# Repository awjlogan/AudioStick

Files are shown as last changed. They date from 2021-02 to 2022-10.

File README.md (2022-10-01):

# AudioStick

Quality audio carrier board for the Raspberry Pi Zero. A self facilitating media node.

## Description and Getting Started

This board is designed to be used with a Raspberry Pi Zero (W) to turn it into small high quality streaming audio device. It incorporates a soft power switch, which makes it easier to use in normal settings (e.g., don't need to SSH in to shutdown) and prolong the life of the SD card. The AudioStick connects directly to the standard Raspberry Pi 40pin GPIO header.

All design files and source code are under the [_Don't Be A Dick_][dbad-github] license.

### Installation on the Raspberry Pi

From a clean installation of Raspbian, log in to your Raspberry Pi and run the following 3 lines:

```shell
> sudo apt install git
> git clone https://github.com/awjlogan/audiostick.git
> cd ./audiostick
> sudo ./audiostick_setup.sh
```

The `audiostick_setup.sh` script will:
 - Install the PCM5102's configuration in the boot configuration
 - Add the `asound.conf` configuration file
 - Add the power control service
 - Shutdown the Raspberry Pi

When it is complete, you will need to remove and reconnect the power before powering on again.

### Using the AudioStick

 - When the AudioStick is off, there is no power supplied to the Raspberry Pi, so power consumption is minimised.
 - Pressing the button will power on the Raspberry Pi. The power LED will flash until the Raspberry Pi has successfully booted, at which point it will stay on.
 - To turn the AudioStick OFF, press and hold the button for at least one second. The power LED will flash until the Raspberry Pi has safely shutdown. Once the LED returns to pulsing, the Raspberry Pi is completely off and it is safe to remove the power if you wish.

### Raspberry Pi Setup

The AudioStick is intended to be used with something like MPD to allow you to connect up to any speaker (with amplifier) and get access to your local music or streaming services controlled by your phone. There are a lot of good tutorials (REVISIT add some links) available, so I won't reiterate the points here, but here are a few additional things that might be useful:

 - Change the Raspberry Pi's hostname to a meaningful name, for example `livingroompi`. This will also allow you to have multiple AudioSticks on the same network.
 - Configure your NAS (or whatever storage) to mount at boot time in `/etc/fstab`. Be aware that the system might attempt to mount the device before the network is available.
 - Disable the swap file to increase the SD card's life (`sudo apt remove dphys-swapfile`)

## Hardware

### PCB

The PCB was designed using [EAGLE][eagle-web] v9. The *.brd* and *.sch* files are provided, along with a small library of parts (*AudioStick.lbr*). A full bill of materials is provided as an *.ods* file.

### Firmware and flashing the ATtiny13A

The source for the power control microcontroller is provided, and can be compiled with the supplied Makefile. You will need to alter `Makefile` with the programmer that you are using. To compile the firmware:

`> /firmware/make`

The header **J4** on the PCB is a standard Microchip \[Atmel\] 6 pin programming header. Using your compiled firmware (or the precompiled *.hex* file), you can flash the microcontroller with e.g. an Atmel ICE. To flash the microcontroller, run:

`> /firmware/make flash`

## Change Notes

### Version 2.2

 - [x] -ELEC- Change from pogo pads to pin header for AVR ISP.

### Version 2.1

 - [x] -MECH- Mirror RasPi so connectors face Audiostick board.
 - [x] -ELEC- Move LED to PWM output pin for more interesting effects (chicken transistor in case programmer can't drive pin with LED).
 - [x] -ELEC- Remove MOSFET power switch for RasPi. Use inrush inhibitor instead.
 - [x] -ELEC- Downsize RasPi power capacitor.

### Version 2.0

Finalised release PCB, firmware, and RasPi software.

## Datasheets and useful links

- [PCM5102 DAC][pcm5102-datasheet]
- [ATtiny13A][attiny13-datasheet]

[dbad-github]: https://github.com/philsturgeon/dbad
[eagle-web]: https://www.autodesk.com/products/eagle/overview
[pcm5102-datasheet]: http://www.ti.com/product/PCM5102
[attiny13-datasheet]: https://www.microchip.com/wwwproducts/en/ATTINY13A

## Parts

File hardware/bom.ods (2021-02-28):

Designator | Description | Name | Value | Unit | Package | Quantity | Farnell code | Cost per | Cost total | DNP
C2, C4, C7, C10, C11, C12, C13, C15, C19 | Ceramic cap |  | 100 | nF | 0603 | 9 | 2581045 | £0.02 | £0.14
C16 | Ceramic cap |  | 10 | nF | 0603 | 1 |  |  |  | DNP
C3, C5, C6, C14, C17 | Ceramic cap |  | 2.2 | uF | 0603 | 3 | 3013428 | £0.11 | £0.34
C8, C9 | Film cap |  | 2.2 | nF | 0603 | 2 | 2326055 | £0.20 | £0.40
D1, D2, D3 | TVS protection diodes |  |  |  | 0603 | 3 |  |  |  | DNP
IC1 | LDO voltage regulator | AP2127 |  |  | SOT-23-5 | 1 | 3257432 | £0.29 | £0.29
IC2 | LDO voltage regulator | MCP1700 | 3.3 | V | SOT-23 | 1 | 1296592 | £0.31 | £0.31
IC3 | Audio codec | PCM5102A |  |  | SSOP-28 | 1 | 2402251 | £4.64 | £4.64
IC5 | Inrush limiter | AP22804AWS |  |  | SOT-23-5 | 1 | 2748546 | £0.50 | £0.50
IC6 | Microcontroller | Attiny13A |  |  | SOIC-8 | 1 | 1715519 | £0.66 | £0.66
J2 | 3.5mm stereo jack | n/a |  |  |  | 1 | 2579730 | £1.80 | £1.80
J3 | USB micro-B |  |  |  |  | 1 | 2668482 | £0.25 | £0.25
J4 | 2x3 1.27 mm header |  |  |  |  | 1 | 2779463 | £0.64 | £0.64
L1, L2, L3 | Ferrite bead |  |  |  | 0603 | 3 | 1115048 | £0.02 | £0.07
LED1 | LED | KPA-3010 |  |  |  | 1 | 2464007 | £0.14 | £0.14
R1, R2 | Thin film resistor |  | 470 | R | 0603 | 2 | 2614445 | £0.08 | £0.15
R4, R11 | Resistor |  | 180 | R | 0603 | 2 | 2447267 | £0.00 | £0.01
R5, R6, R7, R12, R16 | Resistor |  | 22 | R | 0603 | 5 | 2447301 | £0.01 | £0.03
R3, R9, R10, R13, R14 | Resistor |  | 10 | K | 0603 | 4 | 2447230 | £0.01 | £0.02
R8 | Resistor |  | 0 | R | 0603 | 1 |  |  |  | DNP
Raspberry Pi header | 2x20 pin socket |  |  |  |  | 1 | 2725179 | £0.23 | £0.23
SW1 | SPNO switch | EVQP7C |  |  |  | 1 | 2860917 | £0.25 | £0.25
T1 | NPN transistor | BC850 |  |  | SOT-23 | 1 | 1081239 | £0.04 | £0.25
 |  |  |  |  |  |  |  | Total (ex VAT) | £10.86
 |  |  |  |  |  |  |  | Total (inc VAT) | £13.03
 |  |  |  |  | '

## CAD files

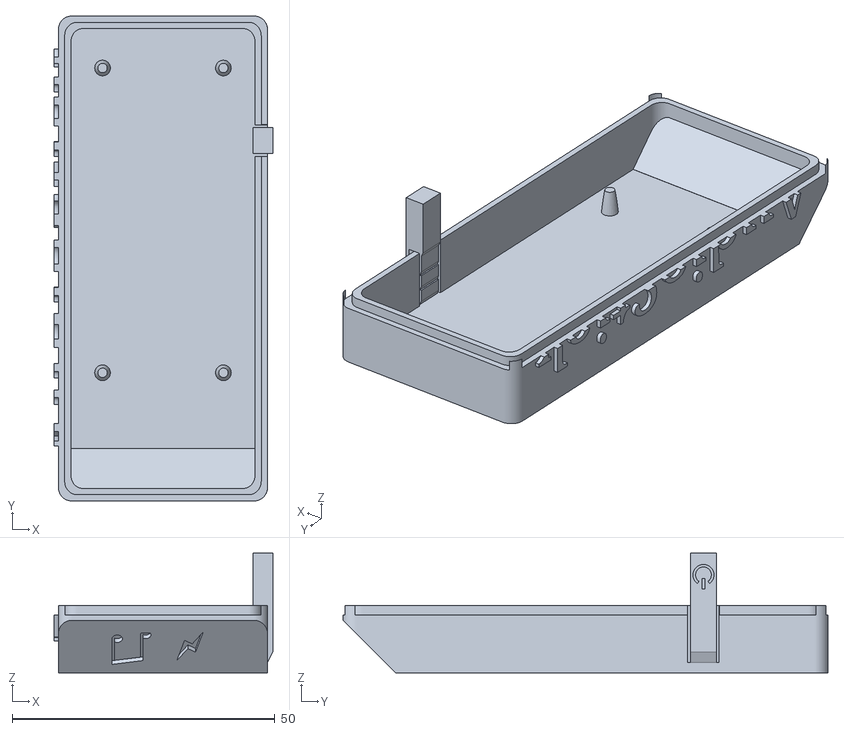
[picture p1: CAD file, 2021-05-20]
hardware/case/case_top.stl
41.6 x 92.3 x 22.8

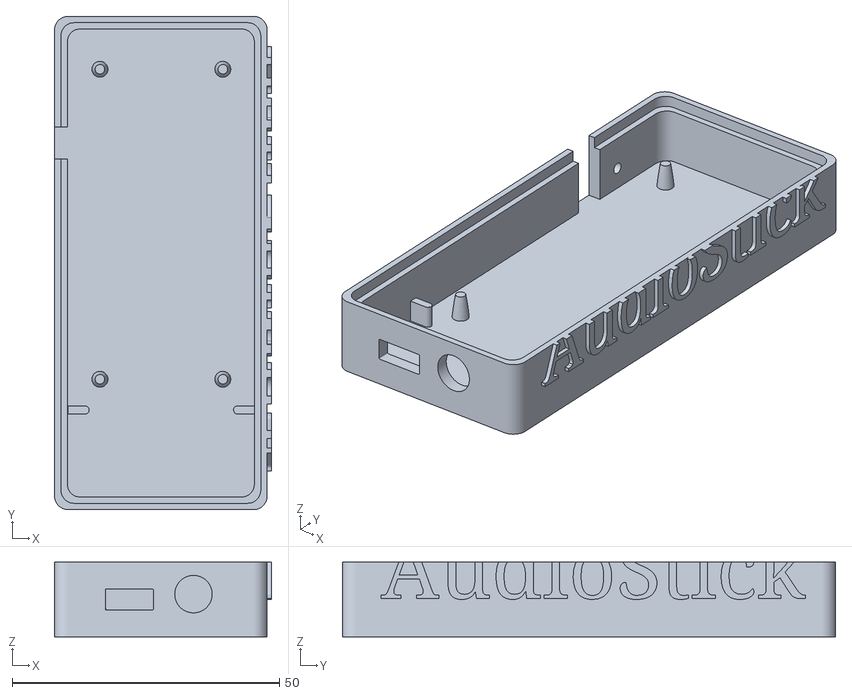
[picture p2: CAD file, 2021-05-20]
hardware/case/case_bottom.stl
40.6 x 92.3 x 14.0

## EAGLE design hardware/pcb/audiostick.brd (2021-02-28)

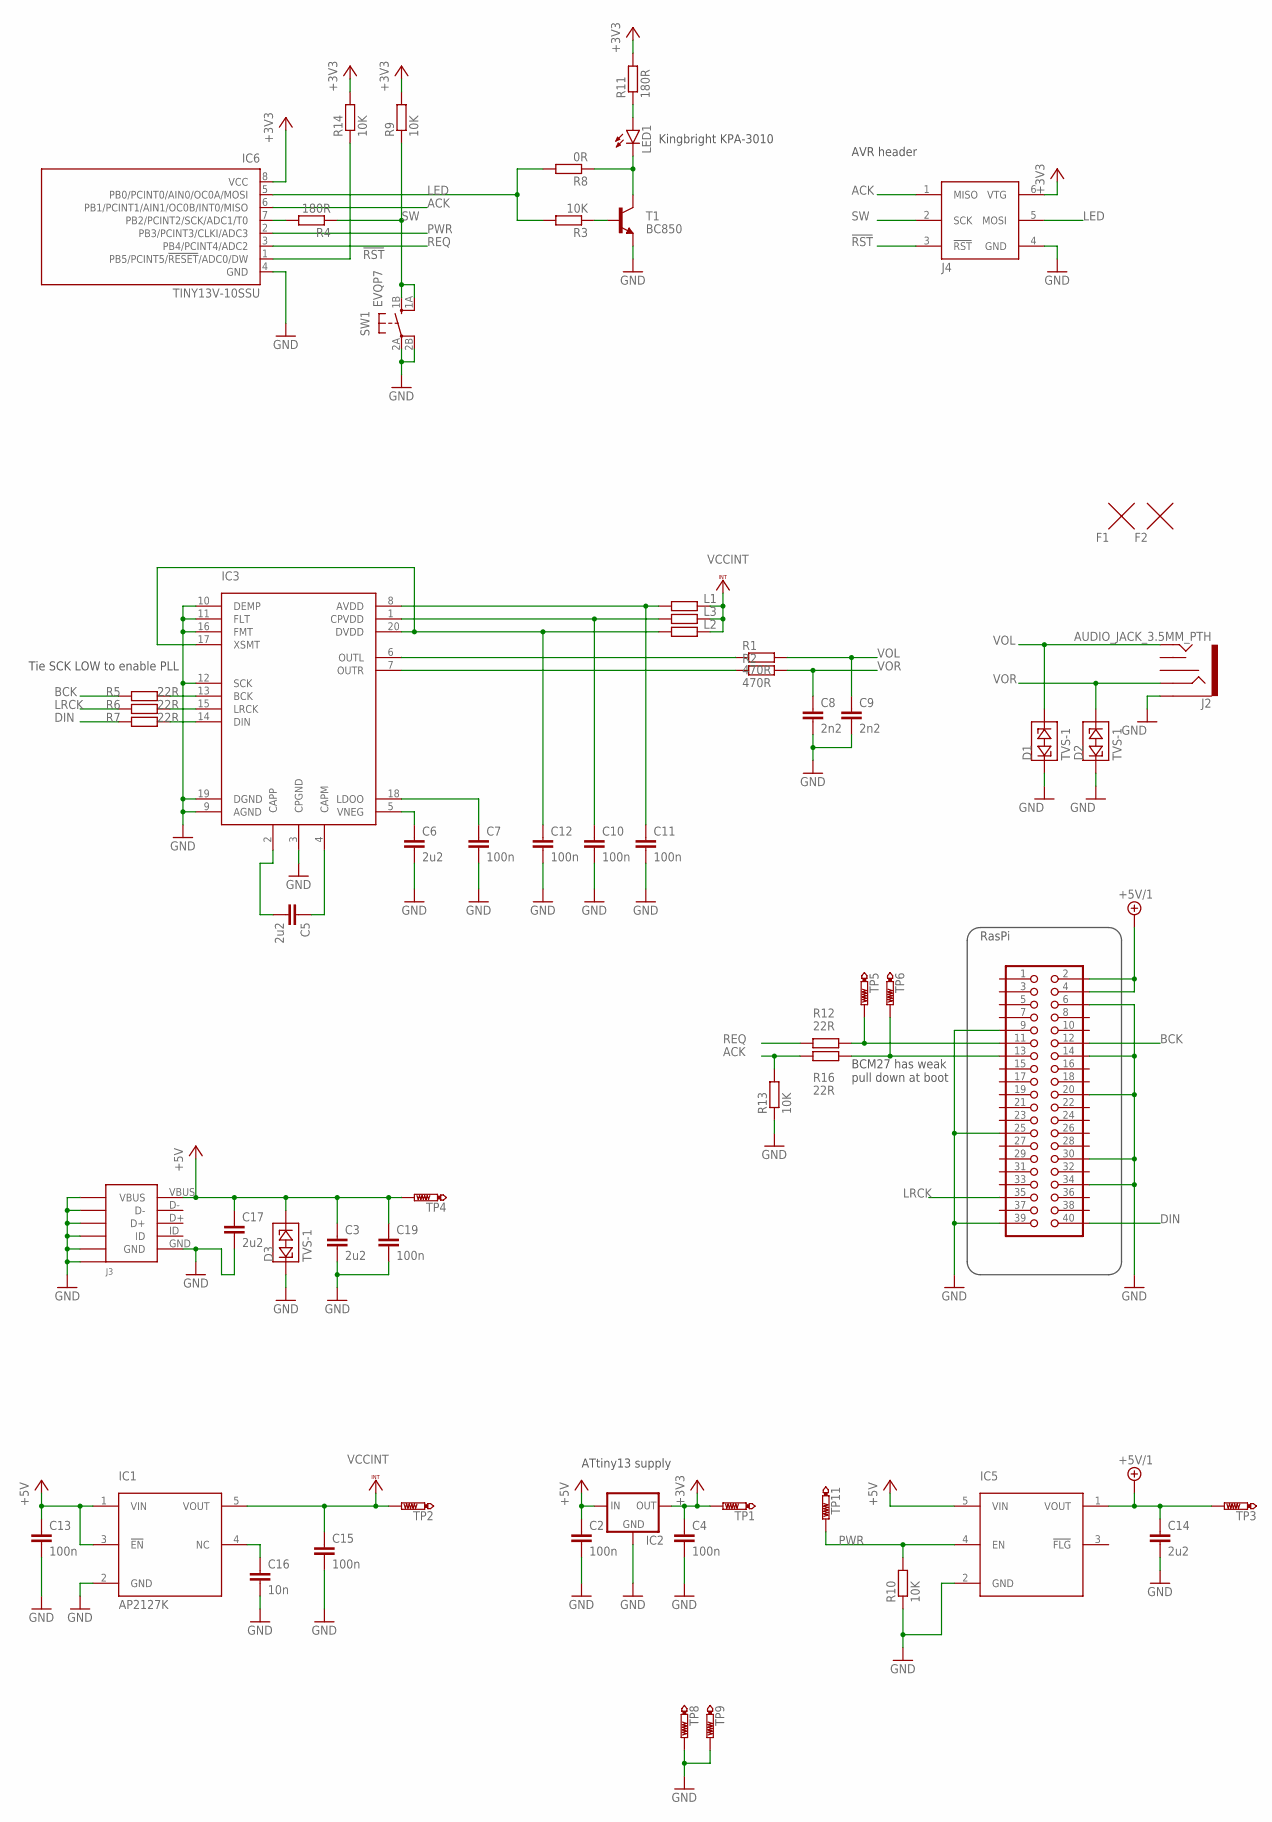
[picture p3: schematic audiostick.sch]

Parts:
C2, C4, C7, C10, C11, C12, C13, C15, C19: 100n; C0603
C3, C5, C6, C14, C17: 2u2; C0603
C8, C9: 2n2; C0603
C16: 10n; C0603
D1, D2, D3: TVS-1; R0603
F1, F2: FIDUCIALC2; CIRCLE-1MM-3R
IC1: AP2127K; GHI_SOT23-5
IC2: MCP1700TT; SOT-23
IC3: PCM5102ASW; TSSOP20
IC5: AP22804W5; GHI_SOT23-5
IC6: TINY13V-10SSU; 8S1
J2: AUDIO_JACK_3.5MM_PTH; AUDIO-JACK
J3: USB-B; 1050170001
J4: AVRISP; 2X3-1.27
L1, L2, L3: F; R0603
LED1: LEDLED; KPA-3010
R1, R2: 470R; R0603
R3, R9, R10, R13, R14: 10K; R0603
R4, R11: 180R; R0603
R5, R6, R7, R12, R16: 22R; R0603
R8: 0R; R0603
SW1: EVQP7; EVQP7L
T1: BC850; SOT23
TP1, TP2, TP3, TP4, TP5, TP6, TP8, TP9, TP11: PTR1PAD1-13; P1-13
U$1: RASPIZERO

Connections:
!RST: IC6.1 (PB5/PCINT5/!RESET!/ADC0/DW), J4.3 (!RST), R14.1
+3V3: C4.1, IC2.2 (OUT), IC6.8 (VCC), J4.6 (VTG), R9.2, R11.2, R14.2, TP1.TP
+5V: C2.1, C3.1, C13.1, C17.1, C19.1, D3.2 (3), IC1.1 (VIN), IC1.3 (!EN), IC2.3 (IN), IC5.5 (VIN), J3.VBUS, TP4.TP
+5V/1: C14.1, IC5.1 (VOUT), TP3.TP, U$1.2 (5V), U$1.4 (5V)
ACK: IC6.6 (PB1/PCINT1/AIN1/OC0B/INT0/MISO), J4.1 (MISO), R13.2, R16.1
ACK_IN: R16.2, TP6.TP, U$1.13 (27)
BCK: R5.1, U$1.12 (18)
DIN: R7.1, U$1.40 (21)
GND: C2.2, C3.2, C4.2, C6.2, C7.2, C8.2, C9.2, C10.2, C11.2, C12.2, C13.2, C14.2, C15.2, C16.2, C17.2, C19.2, D1.1, D2.1, D3.1, IC1.2 (GND), IC2.1 (GND), IC3.3 (CPGND), IC3.9 (AGND), IC3.10 (DEMP), IC3.11 (FLT), IC3.12 (SCK), IC3.16 (FMT), IC3.19 (DGND), IC5.2 (GND), IC6.4 (GND), J2.SLEEVE, J3.GND, J3.P$1 (SH1*4), J3.P$2 (SH1*1), J3.P$3 (SH1*2), J3.P$4 (SH1*3), J3.P$10 (SH1*5), J3.P$11 (SH1*6), J4.4 (GND), R10.1, R13.1, SW1.2A, SW1.2B (P1), T1.2 (E), TP8.TP, TP9.TP, U$1.6 (GND), U$1.9 (GND), U$1.14 (GND), U$1.20 (GND), U$1.25 (GND), U$1.30 (GND), U$1.34 (GND), U$1.39 (GND)
LED: IC6.5 (PB0/PCINT0/AIN0/OC0A/MOSI), J4.5 (MOSI), R3.2, R8.2
LRCK: R6.1, U$1.35 (19)
unnamed: C5.1, IC3.4 (CAPM)
unnamed: C5.2, IC3.2 (CAPP)
unnamed: C6.1, IC3.5 (VNEG)
unnamed: C7.1, IC3.18 (LDOO)
unnamed: IC3.6 (OUTL), R1.1
unnamed: R3.1, T1.1 (B)
unnamed: C11.1, IC3.8 (AVDD), L1.1
unnamed: IC3.7 (OUTR), R2.1
unnamed: IC3.13 (BCK), R5.2
unnamed: IC3.15 (LRCK), R6.2
unnamed: IC3.14 (DIN), R7.2
unnamed: C12.1, IC3.17 (XSMT), IC3.20 (DVDD), L2.1
unnamed: C10.1, IC3.1 (CPVDD), L3.1
unnamed: LED1.C, R8.1, T1.3 (C)
unnamed: C16.1, IC1.4 (NC)
unnamed: LED1.A, R11.1
unnamed: IC6.7 (PB2/PCINT2/SCK/ADC1/T0), R4.2
PWR: IC5.4 (EN), IC6.2 (PB3/PCINT3/CLKI/ADC3), R10.2, TP11.TP
REQ: IC6.3 (PB4/PCINT4/ADC2), R12.1
SW: J4.2 (SCK), R4.1, R9.1, SW1.1A (S1), SW1.1B (S)
S_REQ': R12.2, TP5.TP, U$1.11 (17)
VCCINT: C15.1, IC1.5 (VOUT), L1.2, L2.2, L3.2, TP2.TP
VOL: C9.1, D1.2 (3), J2.TIP, R1.2
VOR: C8.1, D2.2 (3), J2.RING, R2.2

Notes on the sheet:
Tie SCK LOW to enable PLL
BCM27 has weak pull down at boot
ATtiny13 supply
Kingbright KPA-3010
AVR header

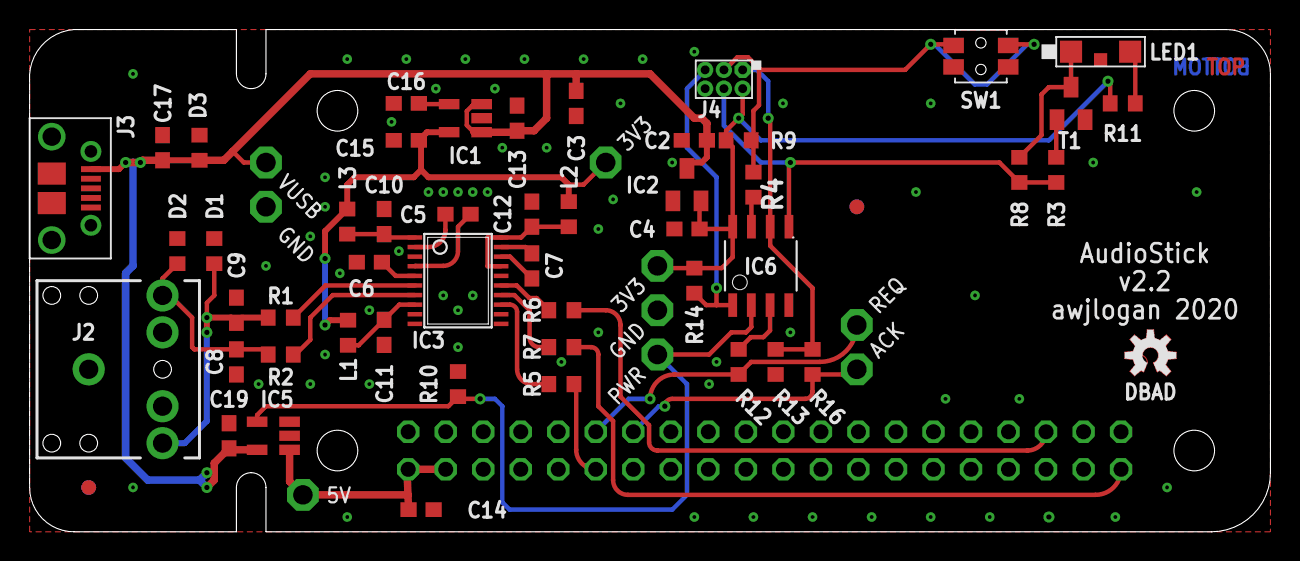
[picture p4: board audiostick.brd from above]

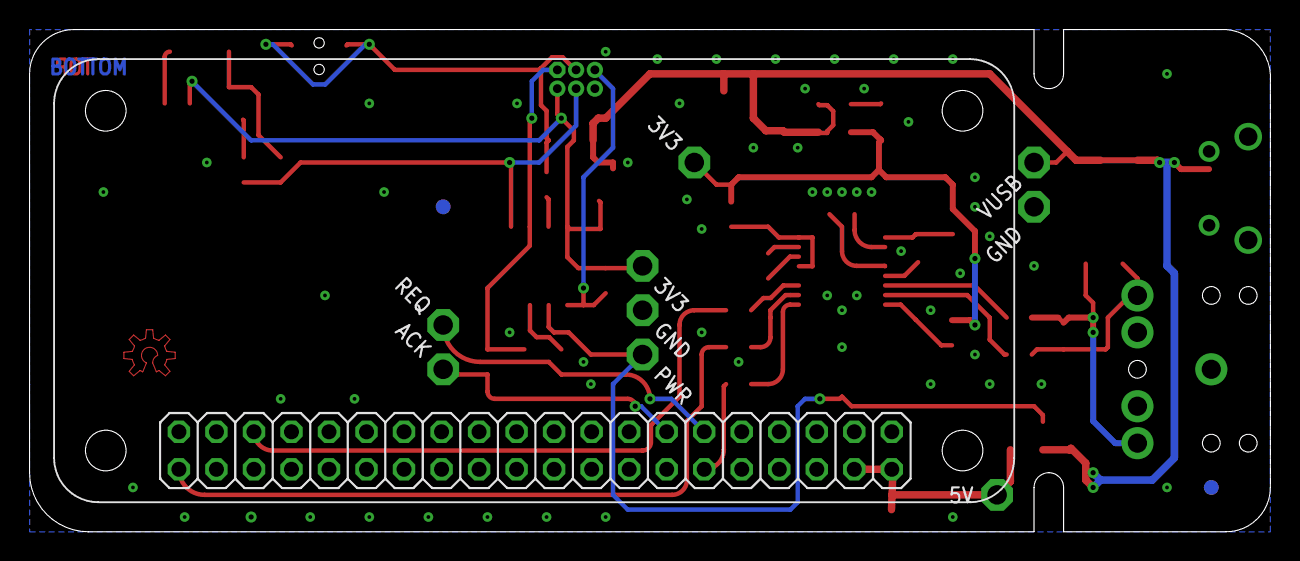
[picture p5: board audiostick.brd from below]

Board: 2 copper layers, 84.0 x 34.0 mm, 61 parts (2 on the bottom side), 35 nets.

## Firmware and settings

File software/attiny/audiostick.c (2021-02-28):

/*

> Copyright (C) 2020-21 Angus Logan

 Everyone is permitted to copy and distribute verbatim or modified
 copies of this license document.

> DON'T BE A DICK PUBLIC LICENSE
> TERMS AND CONDITIONS FOR COPYING, DISTRIBUTION AND MODIFICATION

 1. Do whatever you like with the original work, just don't be a dick.

     Being a dick includes - but is not limited to - the following instances:

     1a. Outright copyright infringement - Don't just copy the original work/works and change the name.
     1b. Selling the unmodified original with no work done what-so-ever, that's REALLY being a dick.
     1c. Modifying the original work to contain hidden harmful content. That would make you a PROPER dick.

 2. If you become rich through modifications, related works/services, or supporting the original work,
 share the love. Only a dick would make loads off this work and not buy the original work's
 creator(s) a pint.

 3. Code is provided with no warranty. Using somebody else's code and bitching when it goes wrong makes
 you a DONKEY dick. Fix the problem yourself. A non-dick would submit the fix back or submit a bug report

 * Author:  Angus Logan
 * Version: 2.1, 2.2
 * Date:    March 2020
 * Target:  Microchip [Atmel] ATtiny13A
 *
 * Physical <-> logical pin mapping
 *
 * Package: SOIC8/DIP8
 * Physical     Function        Logical     i/o
 *----------------------------------------------
 *  1           !RST            PB5         i
 *  2           PWR             PB3         o
 *  3           LED             PB0         o
 *  4           < GND >                     -
 *  5           REQ             PB4         o
 *  6           ACK             PB1         i
 *  7           SW              PB2         i
 *  8           < VDD >                     -
 *
 */

#include <avr/io.h>
#include <avr/interrupt.h>
#include <avr/sleep.h>

#include <stdbool.h>
#include <stdint.h>

#include "audiostick.h"

// ISRs
EMPTY_INTERRUPT (TIM0_OVF_vect)             // Timer0 overflow just wakes up

static inline void
setup_avr(void)
{
    /*  Clocking
        F_CPU = 9.6 MHz / 4 = 2.4 MHz
        Set top bit 1 and then write within 4 cycles
    */
    cli();
    CLKPR = (0x1U << CLKPCE);
    CLKPR = (0x1U << CLKPS1);
    sei();

    /* Interrupts: default */

    /* Timer0 */
    /* Overflow every INT_PER ms */
    TCCR0B = (0x1U << CS01);  // clk / 8 -> 1.176 kHz overflow
    TIMSK0 = (0x1U << TOIE0); // Interrupt on overflow

    /* Port B: */
    MCUCR = (0x1U << PUD);  // disable pull ups
    // Configure outputs
    DDRB = (0x1U << REQ) | (0x1U << PWR) | (0x1U << LED);

    /* Power reduction */
    PRR = (0x1U << PRADC);  // ADC off
    ACSR = (0x1U << ACD);  // analog comparator off
}

static inline void
update_sw(const struct Count_Overflows *p_cnt_ovf, bool *p_sw_pressed)
{

    static uint8_t sw_debounce = SW_OPEN;

    if (p_cnt_ovf->debounce > OVF_CNT_DEBOUNCE) {

        // Shift left, and add switch input (open == HIGH)
        sw_debounce = sw_debounce << 1;
        if (PINB & (0x1U << SW)) {
            sw_debounce++;
        }

        if (sw_debounce == SW_CLOSED) {
            *p_sw_pressed = true;
        } else if (sw_debounce == SW_OPEN) {
            *p_sw_pressed = false;
        }
    }
}

static inline void
update_fsm(power_fsm_t *p_fsm_state, const struct Count_Overflows *p_cnt_ovf, bool sw_pressed)
{

    switch (*p_fsm_state) {
        case OFF:

            *p_fsm_state = sw_pressed ? START : OFF;
            break;

        case START:

            *p_fsm_state = (PINB & (0x1U << ACK)) ? ON : START;
            *p_fsm_state = (p_cnt_ovf->err_wait > OVF_CNT_ERROR) ? ERROR : *p_fsm_state;
            break;

        case ON:

            // Button must be pressed and held
            *p_fsm_state = (p_cnt_ovf->off_press > OVF_CNT_OFF_PRESS) ? STOP : ON;
            break;

        case STOP:

            *p_fsm_state = (!(PINB & (0x1U << ACK))) ? OFF : STOP;
            *p_fsm_state = (p_cnt_ovf->err_wait > OVF_CNT_ERROR) ? ERROR : *p_fsm_state;
            break;

        case ERROR:

            // Button must be held 3X off_press to reset to OFF
            *p_fsm_state = (p_cnt_ovf->off_press > 3 * OVF_CNT_OFF_PRESS) ? OFF : ERROR;

        default:
            break;
    }
    return;
}

void
update_counters(const power_fsm_t *p_fsm_state, struct Count_Overflows *p_cnt_ovf, const bool *p_sw_pressed)
{

    // Update debounce counter in all states
    if (p_cnt_ovf->debounce > OVF_CNT_DEBOUNCE) {
        p_cnt_ovf->debounce = 0x00U;
    } else {
        p_cnt_ovf->debounce++;
    }

    switch (*p_fsm_state) {

        case OFF:

            p_cnt_ovf->off_press = 0x0000U;
            break;

        case ON:

            p_cnt_ovf->err_wait = 0x0000U;

            // Switch must be pressed and held
            if (*p_sw_pressed) {
                p_cnt_ovf->off_press++;
            } else {
                p_cnt_ovf->off_press = 0x0000U;
            }
            break;

        case START:

            p_cnt_ovf->err_wait++;

            if (p_cnt_ovf->led_flash > OVF_CNT_LED_PULSE) {
                p_cnt_ovf->led_flash = 0x0000U;
            } else {
                p_cnt_ovf->led_flash++;
            }
            break;

        case STOP:

            p_cnt_ovf->err_wait++;

            if (p_cnt_ovf->led_flash > OVF_CNT_LED_PULSE) {
                p_cnt_ovf->led_flash = 0x0000U;
            } else {
                p_cnt_ovf->led_flash++;
            }

            // Reset button press for OFF counter
            p_cnt_ovf->off_press = 0x0000U;
            break;

        case ERROR:

            // LED flasher, just let overflow
            p_cnt_ovf->err_flash++;

            p_cnt_ovf->err_wait = 0x0000U;

            if (*p_sw_pressed) {
                p_cnt_ovf->off_press++;
            } else {
                p_cnt_ovf->off_press = 0x0000U;
            }

        default:
            break;
    }
    return;
}

void
pulse_led_update(const struct Count_Overflows *p_cnt_ovf)
{

    static bool cnt_up = true;
    static uint8_t idx = 0;

    // LED PWM values
    const uint8_t pwm_values[16] = {0, 2, 4, 8,
                                    16, 24, 32, 40,
                                    56, 72, 88, 106,
                                    138, 170, 202, 255};

    // Enable the compare-match output on OCOA
    // Fast PWM, output on OCOA
    TCCR0A = (0x1U << COM0A1) | (0x1U << WGM01) | (0x1U << WGM00);

    // Set PWM value
    if (p_cnt_ovf->led_flash > OVF_CNT_LED_PULSE) {
        OCR0A = pwm_values[idx];

        // Generate index into array
        if (cnt_up) {
            idx++;
            if (idx == 15) {
                cnt_up = false;
            }
        } else {
            idx--;
            if (idx == 0) {
                cnt_up = true;
            }
        }
    }
}

static inline void
update_outputs(const power_fsm_t *p_fsm_state, const struct Count_Overflows *p_cnt_ovf)
{

    switch (*p_fsm_state) {
        case OFF:

            // Disable PWM, everything OFF
            TCCR0A = (0x1U << WGM01) | (0x1U << WGM00);
            PORTB = 0x00U;
            break;

        case START:

            PORTB |= (0x1U << PWR) | (0x1U << REQ);
            pulse_led_update(p_cnt_ovf);
            break;

        case ON:

            // Disable LED PWM, set ON
            TCCR0A = (0x1U << WGM01) | (0x1U << WGM00);
            PORTB |= (0x1U << LED);
            break;

        case STOP:

            PORTB &= ~(0x1U << REQ);
            pulse_led_update(p_cnt_ovf);
            break;

        case ERROR:

            TCCR0A = (0x1U << WGM01) | (0x1U << WGM00);
            if (p_cnt_ovf->err_flash == 0) {
                PORTB ^= (0x1U << LED);
            }
            break;

        default:
            break;
    }
    return;
}



// Super loop
int
main(void)
{

    power_fsm_t fsm_state = OFF;          // Start in OFF, stops wakeup on power cut etc
    bool sw_pressed = false;
    struct Count_Overflows cnt_ovf = {0}; // Init all counters to 0

    setup_avr();

    /* Forever */
    for (;;) {

        update_sw(&cnt_ovf, &sw_pressed);
        update_counters(&fsm_state, &cnt_ovf, &sw_pressed);
        update_fsm(&fsm_state, &cnt_ovf, sw_pressed);
        update_outputs(&fsm_state, &cnt_ovf);

        // Sleep and wait for TIM0 interrupt
        sleep_enable();
        sleep_cpu();
        sleep_disable();
    }
}

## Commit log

2019-06-14 First commit of project files
    README to be updated.
    [BOM.ods, audio_stick_1_0.sch, audiostick_1_0.brd]
2019-08-12 Added (untested) Pi side scripts
    [BOM.ods, audio_stick_1_0.sch, audiostick_1_0.brd]
2019-10-13 Added initial BOM, update of README, added Makefile STILL NOT TESTED!
    [bom.ods]
2020-01-04 first v2 commit
    [audiostick_v1.brd, audiostick_v1.sch, bom.ods]
2020-01-13 v2.0 changes
    [audiostick.brd, audiostick.sch, audiostick_v1.brd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]
2020-01-13 Resolve symlink
    [audiostick.brd, audiostick.sch]
2020-01-16 Complete revision of design - layout, connections, parts. Ready for proto run
    [audiostick.brd, audiostick.sch]
2020-01-16 Moved text slightly
    [audiostick.brd]
2020-01-20 Final revision before manufacture
    [audiostick.brd, audiostick.sch]
2020-01-22 Moved vias for standoffs
    [audiostick.brd]
2020-03-16 Update BOM, start updating readme
    [bom.ods]
2020-03-26 Some PWM effect playing
2020-04-17 Fix short exit from STOP_WAIT state - overflow error
    [audiostick.c, audiostick.h]
2020-04-18 chmod for mds, add laser cut path
2020-08-11 Added rendered schematic
2020-08-31 2.0 -> 2.1 simplification, PCB rearrangement
    [audiostick.brd, audiostick.sch]
2020-09-01 Change switch
    [audiostick.brd, audiostick.sch]
2020-09-01 Fix airwire and clearance
    [audiostick.brd]
2020-09-02 Rationalised BOM a little
    [audiostick.brd, audiostick.sch]
2020-09-02 Update BOM
    [audiostick.brd, bom.ods]
2020-09-09 Revert to EVQ switch
    [audiostick.brd, audiostick.sch]
2020-09-09 Change switch in BOM
    [bom.ods]
2020-11-23 Update board, BOM, and firmware
    [audiostick.brd, audiostick.sch, bom.ods]
2021-02-15 Real HW in hand
    [bom.ods]
2021-02-15 Changed pogo points for proper header, silly idea!
    [audiostick.brd, audiostick.sch]
2021-02-16 Confirm LED pulse working
2021-02-28 Finish schematic/layout changes
    [BOM.ods, audiostick.brd, audiostick.sch]
2021-02-28 Adding LED pulse effect
    [bom.ods]
2021-05-20 * Add case STLs
    [case_bottom.stl, case_top.stl]
2021-11-02 Disable default sound driver

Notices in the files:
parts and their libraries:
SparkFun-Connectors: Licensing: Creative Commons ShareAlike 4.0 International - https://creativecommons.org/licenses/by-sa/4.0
